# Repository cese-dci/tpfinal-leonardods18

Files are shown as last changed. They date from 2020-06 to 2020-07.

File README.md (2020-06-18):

TP Diseño de Circuitos Impresos [CESE 10Co2019]

Autor: Del Sancio Leonardo Daniel   -  Alumno revisor: Yapura Alberto  - Docente Revisor: Diego Brengi

Nombre del proyecto: MÓDEM ENERGY METER
Descripción del proyecto: Este proyecto consiste en tomar lecturas de tensión y corrientes de equipos trifásicos y trasnsmitirlas por 
Wifi o bluetooth, el circuito integrado ATM90E36 es el encargado de tomar las variables físicas y trasmitirlas al ESP32 por SPI.

------------------------------------------------------------------------------------
El diseño se Realizará en la empresa fabricante de PCB JLCPCB. https://jlcpcb.com/#

En esta página podes realizar prototipos de excelente calidad por 2 dolares. 

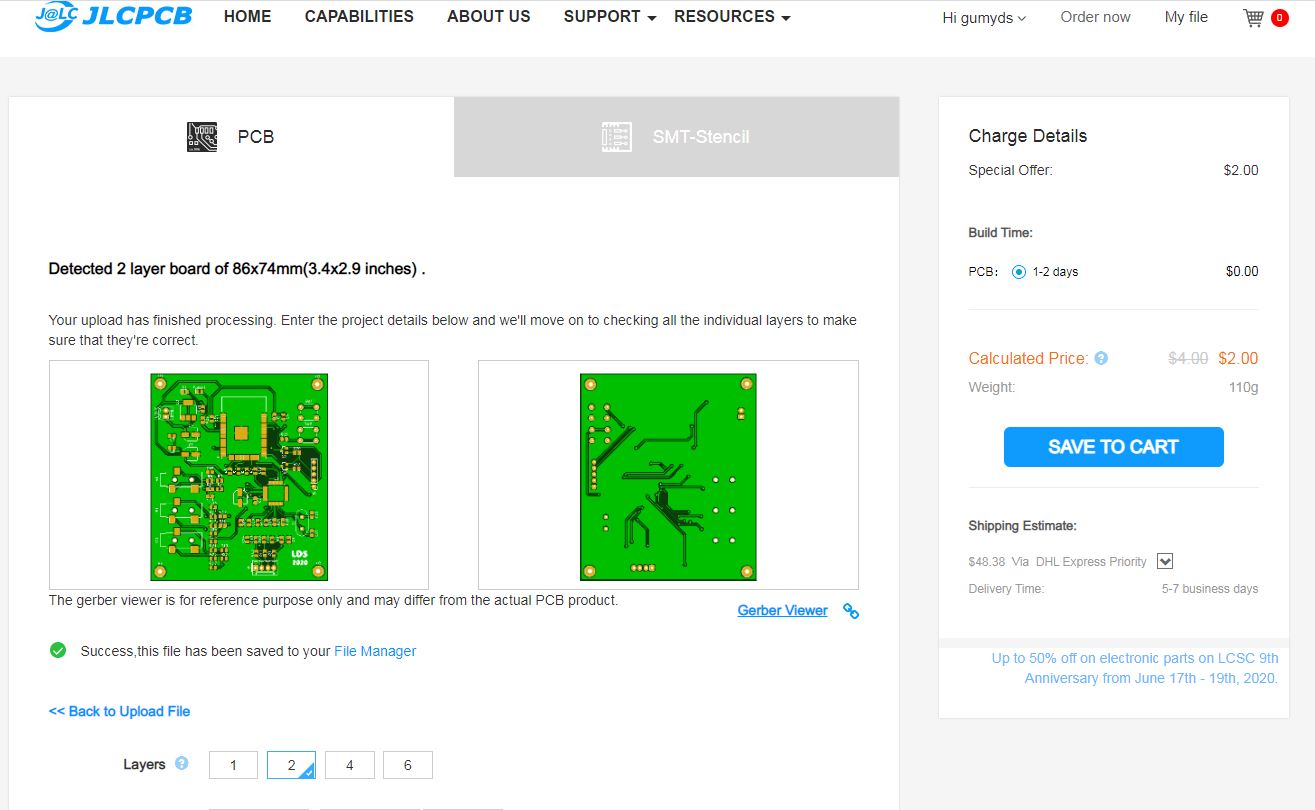
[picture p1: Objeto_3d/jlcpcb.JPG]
Optional Title


------------------------------------------------------------------------------------

NOTA: en el archivo BOM se pueden encontrar todos los componentes y su fabricante de la página MOUSER. 
https://ar.mouser.com/

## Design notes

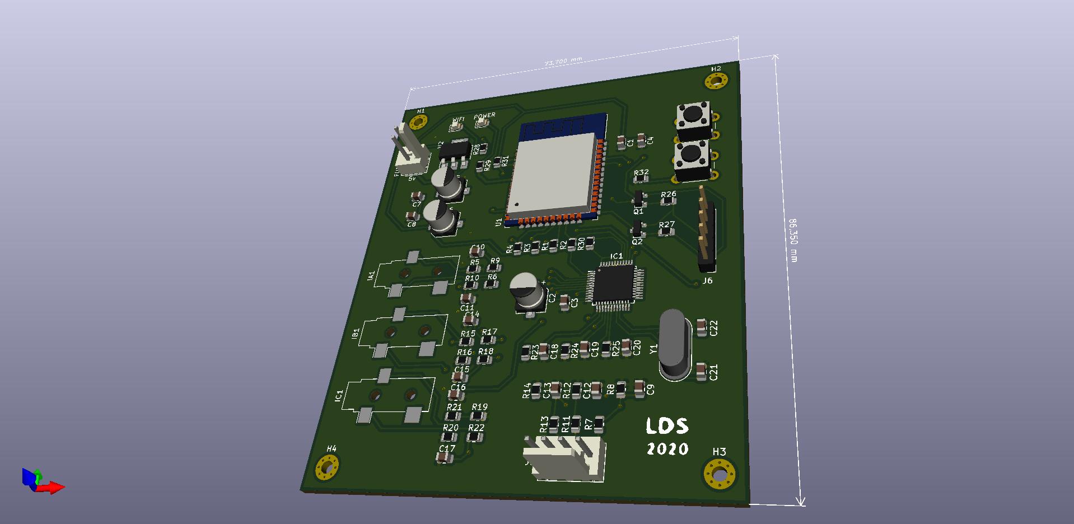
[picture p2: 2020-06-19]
Objeto_3d/Energy_Meter2.jpg

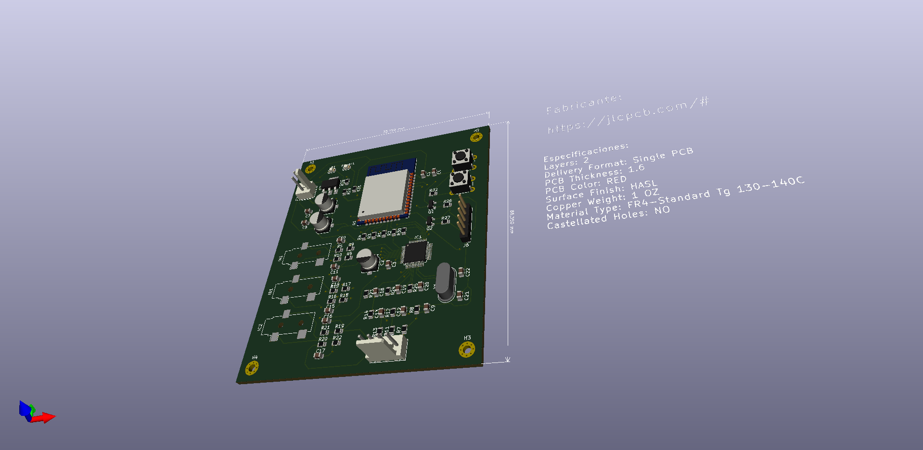
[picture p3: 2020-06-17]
Objeto_3d/Energy_Meter.png

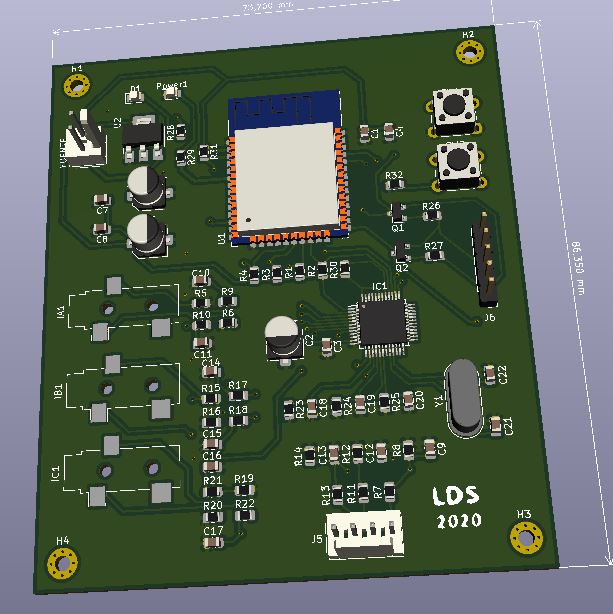
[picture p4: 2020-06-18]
Objeto_3d/Captura.JPG

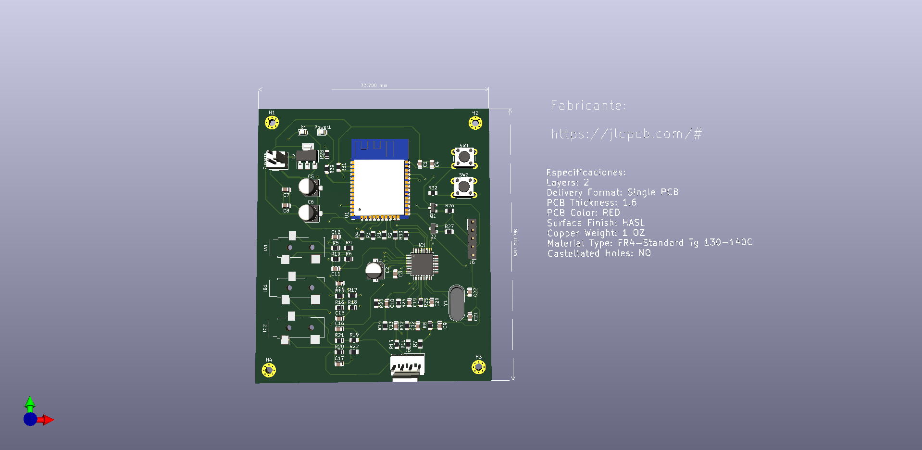
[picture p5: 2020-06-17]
Objeto_3d/Energy_Meter2.png

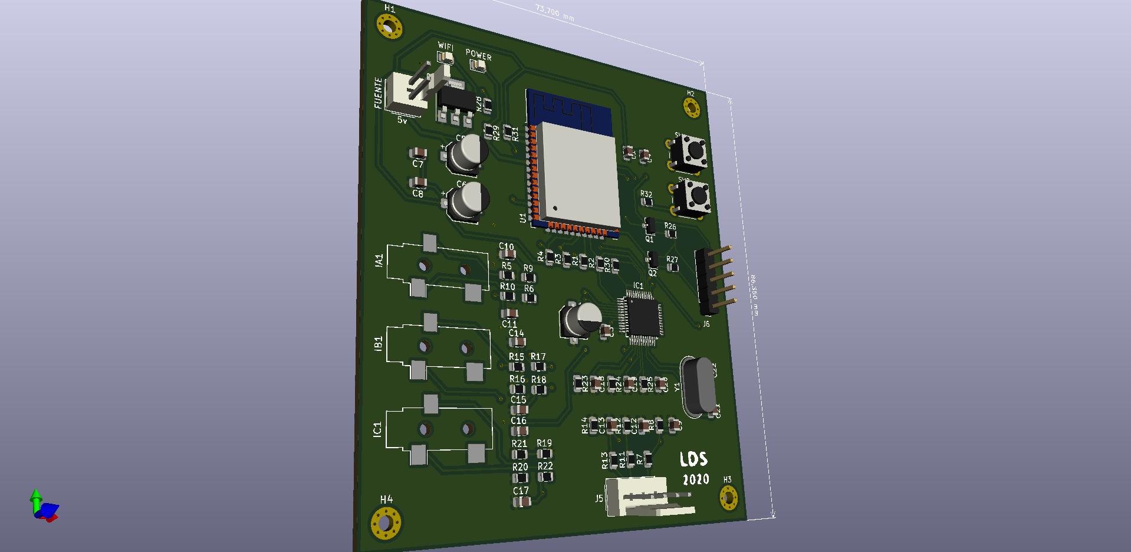
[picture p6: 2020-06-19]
Objeto_3d/Energy_Meter3.jpg

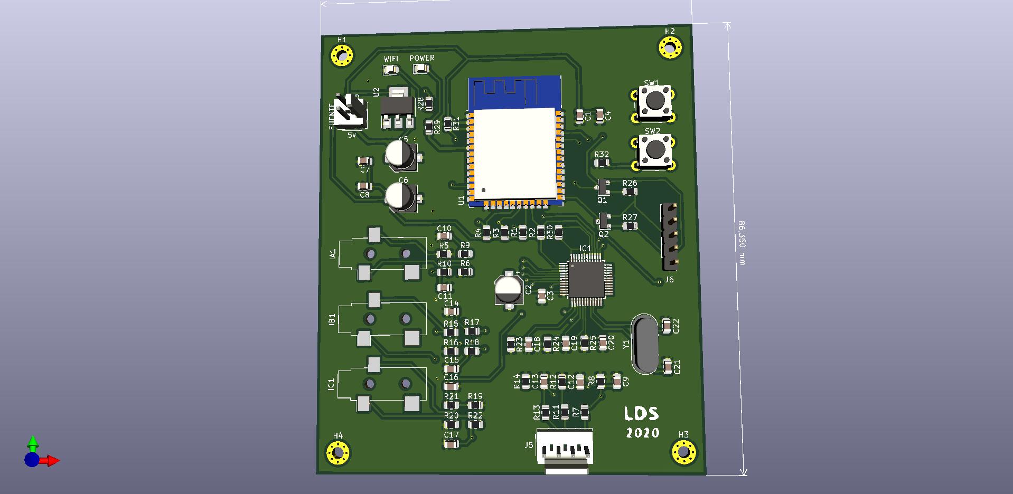
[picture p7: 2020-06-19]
Objeto_3d/Energy_Meter.jpg

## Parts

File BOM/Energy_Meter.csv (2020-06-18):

Id | Identificador | Empaquetado | Cantidad | IdentificaciÃ³n | Fabricante | Descripcion
1 | G*** | fiuba | 1 | LOGO
2 | Y1 | Crystal_HC49-4H_Vertical | 1 | 16.384MHz
3 | U2 | SOT-223-3_TabPin2 | 1 | LD1117S18TR_SOT223
4 | U1 | ESP32-WROOM-32 | 1 | ESP32-WROOM-32D | ESP32-WROOM-32D (4MB) | Módulos WiFi (802.11) SMD Module, ESP32-D0WD, 32Mbits SPI flash, UART mode, PCB
5 | C9,C10,C11,C12,C13,C14,C15,C16,C17,C18,C19,C20 | C_0805_2012Metric | 12 | 18nF | VJ0805Y181KXAPW1BC | Capacitores cerámicos de capas múltiples (MLCC) - SMD/SMT 0805 180pF 50volts
6 | C1,C3,C4,C7 | C_0805_2012Metric | 4 | 100nF | 885012207128 | Capacitores cerámicos de capas múltiples (MLCC) - SMD/SMT WCAP-CSGP 100V 0.1uF 0805 10%
7 | C2,C5,C6 | CP_Elec_5x5.3 | 3 | 10uF
8 | C8 | C_0805_2012Metric | 1 | 47nF
9 | C21,C22 | C_0805_2012Metric | 2 | 22pF
10 | IA1 | Jack_3.5mm_CUI_SJ-3523-SMT_Horizontal | 1 | Corriente A | SJ-3523-SMT-TR | Conectores de teléfono Audio Jacks
11 | IB1 | Jack_3.5mm_CUI_SJ-3523-SMT_Horizontal | 1 | Corriente B | SJ-3523-SMT-TR | Conectores de teléfono Audio Jacks
12 | IC1 | TQFP-48_7x7mm_P0.5mm | 1 | ATM90E36 | ATM90E36A-AU-Y | Entrada analógica - AFE 48-TQFP, IND TEMP 1.8V/3V
13 | IC1 | Jack_3.5mm_CUI_SJ-3523-SMT_Horizontal | 1 | Corriente C | SJ-3523-SMT-TR | Conectores de teléfono Audio Jacks
14 | FUENTE | Molex_KK-254_AE-6410-02A_1x02_P2.54mm_Vertical | 1 | Conn_01x02_Male
15 | J5 | Molex_KK-254_AE-6410-04A_1x04_P2.54mm_Vertical | 1 | TENSION
16 | J6 | PinHeader_1x05_P2.54mm_Vertical | 1 | PROGRAMACION
17 | Q1,Q2 | SOT-23 | 2 | BC817
18 | R1,R2,R3,R4,R26,R27,R30,R31 | R_0805_2012Metric | 8 | 10K
19 | R5,R6,R15,R16,R19,R20 | R_0805_2012Metric | 6 | 2.4
20 | R7,R11,R13 | R_0805_2012Metric | 3 | 100K
21 | R8,R9,R10,R12,R14,R17,R18,R21,R22,R23,R24,R25 | R_0805_2012Metric | 12 | 1K | CRCW08051K00FKEAC | Resistores de película gruesa - SMD 1/8Watt 1Kohms 1%
22 | D1 | LED_0805_2012Metric | 1 | ConexiÃ³n | AP2012HD | LED estándar - SMD (montaje superficial) RED DIFFUSED
23 | Power1 | LED_0805_2012Metric | 1 | LED | AP2012HD | LED estándar - SMD (montaje superficial) RED DIFFUSED
24 | R28,R29 | R_0805_2012Metric | 2 | 560
25 | R32 | R_0805_2012Metric | 1 | 50R
26 | SW1 | SW_PUSH_6mm_H4.3mm | 1 | RESET
27 | SW2 | SW_PUSH_6mm_H4.3mm | 1 | PR
28 | H1,H2,H3,H4 | MountingHole_2.2mm_M2_Pad_Via | 4 | MountingHole

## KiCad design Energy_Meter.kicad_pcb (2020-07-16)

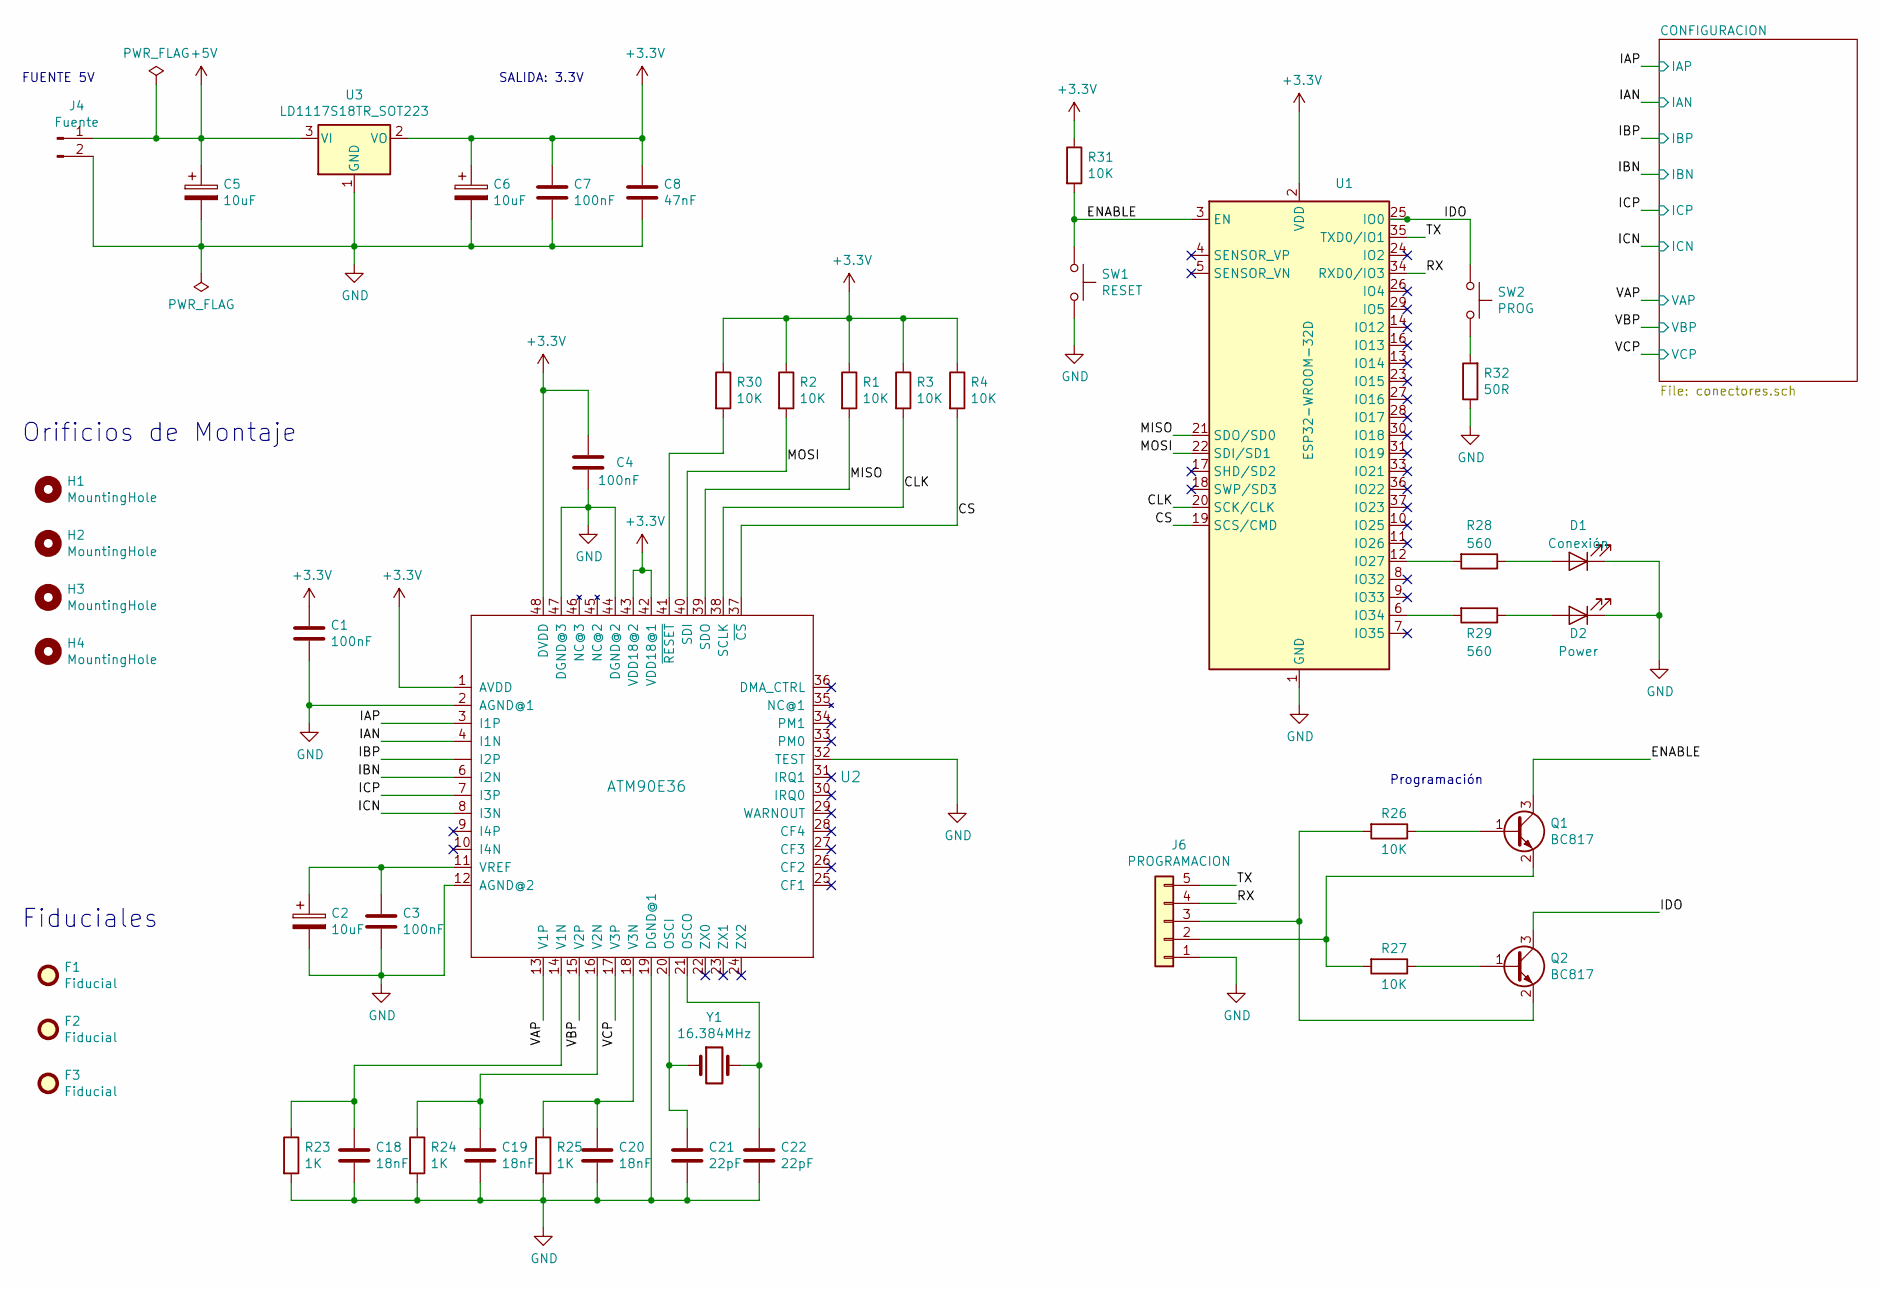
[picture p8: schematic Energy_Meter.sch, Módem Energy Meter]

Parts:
C1, C3, C4, C7: 100nF; C_0805_2012Metric
C2, C5, C6: 10uF; CP_Elec_5x5.3
C8: 47nF; C_0805_2012Metric
C18, C19, C20: 18nF; C_0805_2012Metric
C21, C22: 22pF; C_0805_2012Metric
D1: Conexión; LED_0805_2012Metric
D2: Power; LED_0805_2012Metric
F1, F2, F3: Fiducial; Fiducial_0.5mm_Mask1.5mm
H1, H2, H3, H4: MountingHole; MountingHole_2.2mm_M2_Pad_Via
J4: Fuente; Molex_KK-254_AE-6410-02A_1x02_P2.54mm_Vertical
J6: PROGRAMACION; PinHeader_1x05_P2.54mm_Vertical
Q1: BC817; SOT-23; Mouser 771-BC817K-40HVL
Q2: BC817; SOT-23; Mouser 771-BC817K-16HR
R1, R2, R3, R4, R26, R27, R30, R31: 10K; R_0805_2012Metric
R23, R24, R25: 1K; R_0805_2012Metric
R28, R29: 560; R_0805_2012Metric
R32: 50R; R_0805_2012Metric
SW1: RESET; SW_PUSH_6mm_H4.3mm
SW2: PROG; SW_PUSH_6mm_H4.3mm
U1: ESP32-WROOM-32D; ESP32-WROOM-32; Mouser 356-ESP32WRM32E132PH
U2: ATM90E36; TQFP-48_7x7mm_P0.5mm; Mouser 556-ATM90E36A-AU-Y
U3: LD1117S18TR_SOT223; SOT-223-3_TabPin2; Mouser 511-LD1117AS18
Y1: 16.384MHz; Crystal_HC49-4H_Vertical; Digikey XC2790TR-ND

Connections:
+3V3: C1.1, C4.1, C6.1, C7.1, C8.1, R1.1, R2.1, R3.1, R4.1, R30.1, R31.1, U1.2 (VDD), U2.1 (AVDD), U2.42 (VDD18@1), U2.43 (VDD18@2), U2.48 (DVDD), U3.2 (VO)
+5V: C5.1, J4.1, U3.3 (VI)
/CLK: R3.2, U1.20 (SCK/CLK), U2.38 (SCLK)
/CS: R4.2, U1.19 (SCS/CMD), U2.37 (~CS)
/ENABLE: Q1.3 (C), R31.2, SW1.1, U1.3 (EN)
/IAN: U2.4 (I1N); also elsewhere on the board
/IAP: U2.3 (I1P); also elsewhere on the board
/IBN: U2.6 (I2N); also elsewhere on the board
/IBP: U2.5 (I2P); also elsewhere on the board
/ICN: U2.8 (I3N); also elsewhere on the board
/ICP: U2.7 (I3P); also elsewhere on the board
/IDO: Q2.3 (C), SW2.1, U1.25 (IO0)
/MISO: R1.2, U1.21 (SDO/SD0), U2.39 (SDO)
/MOSI: R2.2, U1.22 (SDI/SD1), U2.40 (SDI)
/RX: J6.4, U1.34 (RXD0/IO3)
/TX: J6.5, U1.35 (TXD0/IO1)
/VAP: U2.13 (V1P); also elsewhere on the board
/VBP: U2.15 (V2P); also elsewhere on the board
/VCP: U2.17 (V3P); also elsewhere on the board
GND: C1.2, C2.2, C3.2, C4.2, C5.2, C6.2, C7.2, C8.2, C18.2, C19.2, C20.2, C21.2, C22.2, D1.1 (K), D2.1 (K), J4.2, J6.1, R23.2, R24.2, R25.2, R32.1, SW1.2, U1.1 (GND), U1.15 (GND), U1.38 (GND), U1.39 (GND), U2.2 (AGND@1), U2.12 (AGND@2), U2.19 (DGND@1), U2.32 (TEST), U2.44 (DGND@2), U2.47 (DGND@3), U3.1 (GND); also elsewhere on the board
unnamed: C2.1, C3.1, U2.11 (VREF)
unnamed: C18.1, R23.1, U2.14 (V1N)
unnamed: C19.1, R24.1, U2.16 (V2N)
unnamed: C20.1, R25.1, U2.18 (V3N)
unnamed: C21.1, U2.20 (OSCI), Y1.1
unnamed: C22.1, U2.21 (OSCO), Y1.2
unnamed: D1.2 (A), R28.1
unnamed: D2.2 (A), R29.1
unnamed: J6.2, Q1.2 (E), R27.2
unnamed: J6.3, Q2.2 (E), R26.2
unnamed: Q1.1 (B), R26.1
unnamed: Q2.1 (B), R27.1
unnamed: R28.2, U1.12 (IO27)
unnamed: R29.2, U1.6 (IO34)
unnamed: R30.2, U2.41 (~RESET)
unnamed: R32.2, SW2.2

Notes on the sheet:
Programación
SALIDA: 3.3V
FUENTE 5V
Orificios de Montaje
Fiduciales

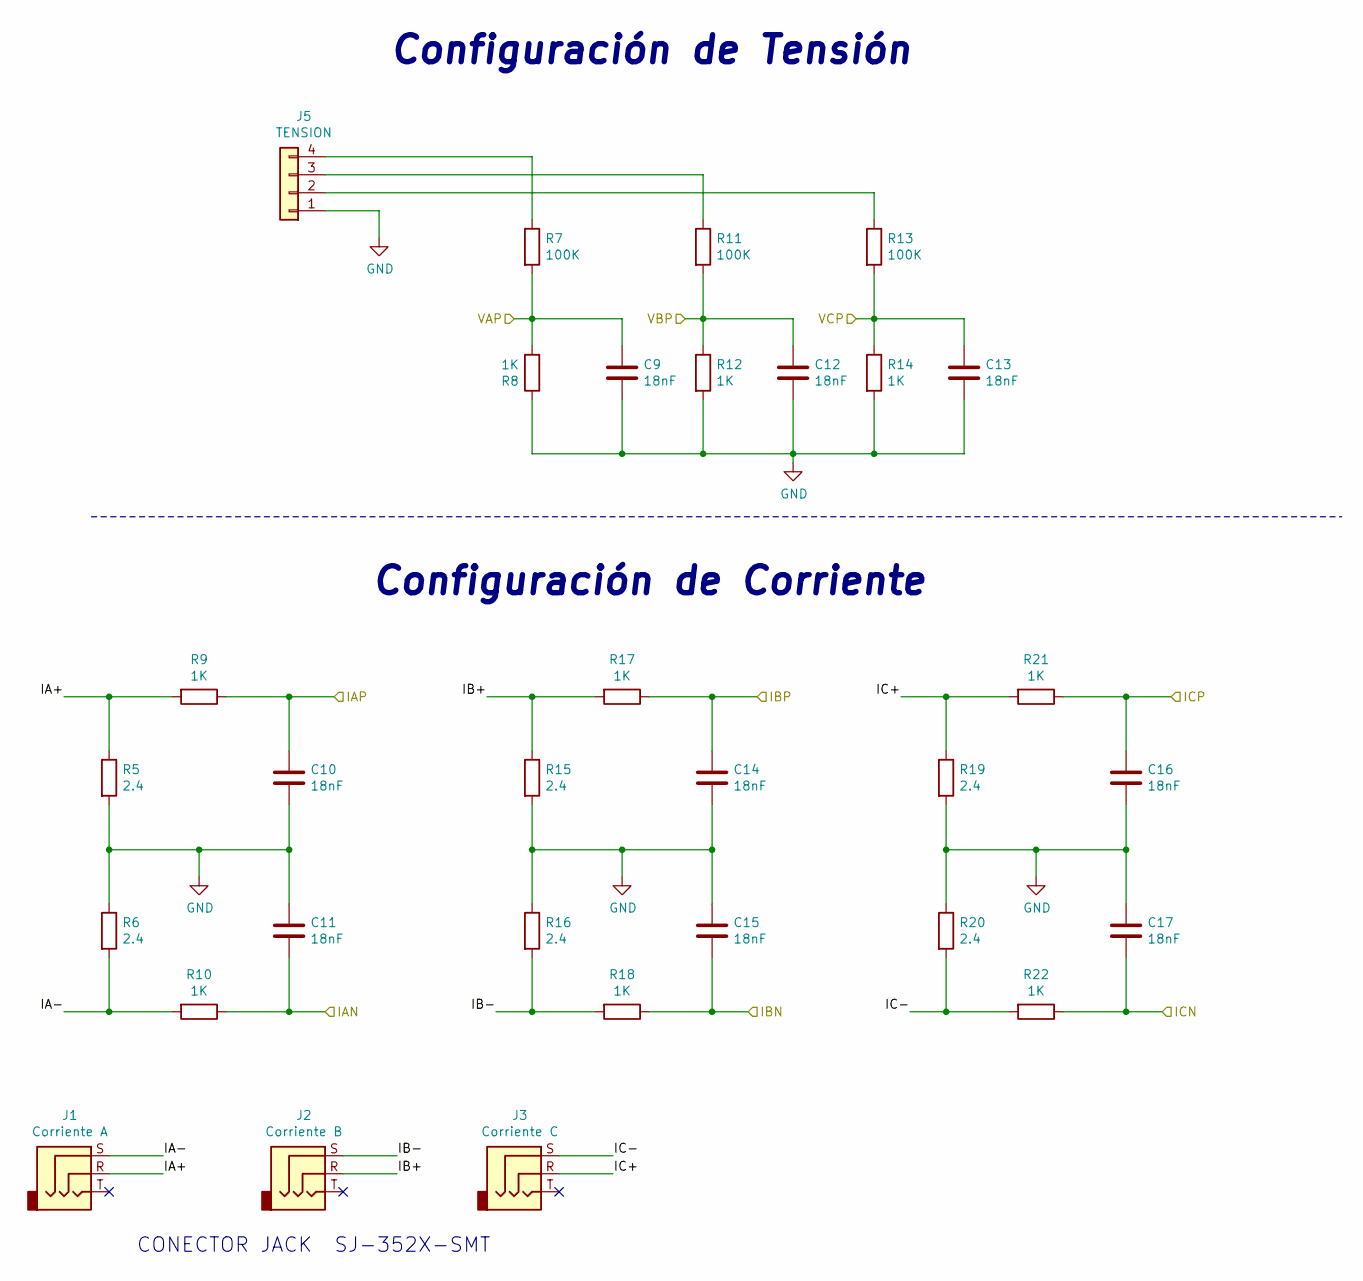
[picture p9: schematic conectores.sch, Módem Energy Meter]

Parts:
C9, C10, C11, C12, C13, C14, C15, C16, C17: 18nF; C_0805_2012Metric
J1: Corriente A; Jack_3.5mm_CUI_SJ-3523-SMT_Horizontal
J2: Corriente B; Jack_3.5mm_CUI_SJ-3523-SMT_Horizontal
J3: Corriente C; Jack_3.5mm_CUI_SJ-3523-SMT_Horizontal
J5: TENSION; Molex_KK-254_AE-6410-04A_1x04_P2.54mm_Vertical
R5, R6, R15, R16, R19, R20: 2.4; R_0805_2012Metric
R7, R11, R13: 100K; R_0805_2012Metric
R8, R9, R10, R12, R14, R17, R18, R21, R22: 1K; R_0805_2012Metric

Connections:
/CONFIGURACION/IA+: J1.R, R5.1, R9.2
/CONFIGURACION/IA-: J1.S, R6.2, R10.2
/CONFIGURACION/IB+: J2.R, R15.1, R17.2
/CONFIGURACION/IB-: J2.S, R16.2, R18.2
/CONFIGURACION/IC+: J3.R, R19.1, R21.2
/CONFIGURACION/IC-: J3.S, R20.2, R22.2
/IAN: C11.2, R10.1; also elsewhere on the board
/IAP: C10.1, R9.1; also elsewhere on the board
/IBN: C15.2, R18.1; also elsewhere on the board
/IBP: C14.1, R17.1; also elsewhere on the board
/ICN: C17.2, R22.1; also elsewhere on the board
/ICP: C16.1, R21.1; also elsewhere on the board
/VAP: C9.1, R7.2, R8.2; also elsewhere on the board
/VBP: C12.1, R11.2, R12.1; also elsewhere on the board
/VCP: C13.1, R13.2, R14.1; also elsewhere on the board
GND: C9.2, C10.2, C11.1, C12.2, C13.2, C14.2, C15.1, C16.2, C17.1, J5.1, R5.2, R6.1, R8.1, R12.2, R14.2, R15.2, R16.1, R19.2, R20.1; also elsewhere on the board
unnamed: J5.2, R13.1
unnamed: J5.3, R11.1
unnamed: J5.4, R7.1

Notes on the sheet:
Configuración de Tensión
CONECTOR JACK SJ-352X-SMT
Configuración de Corriente

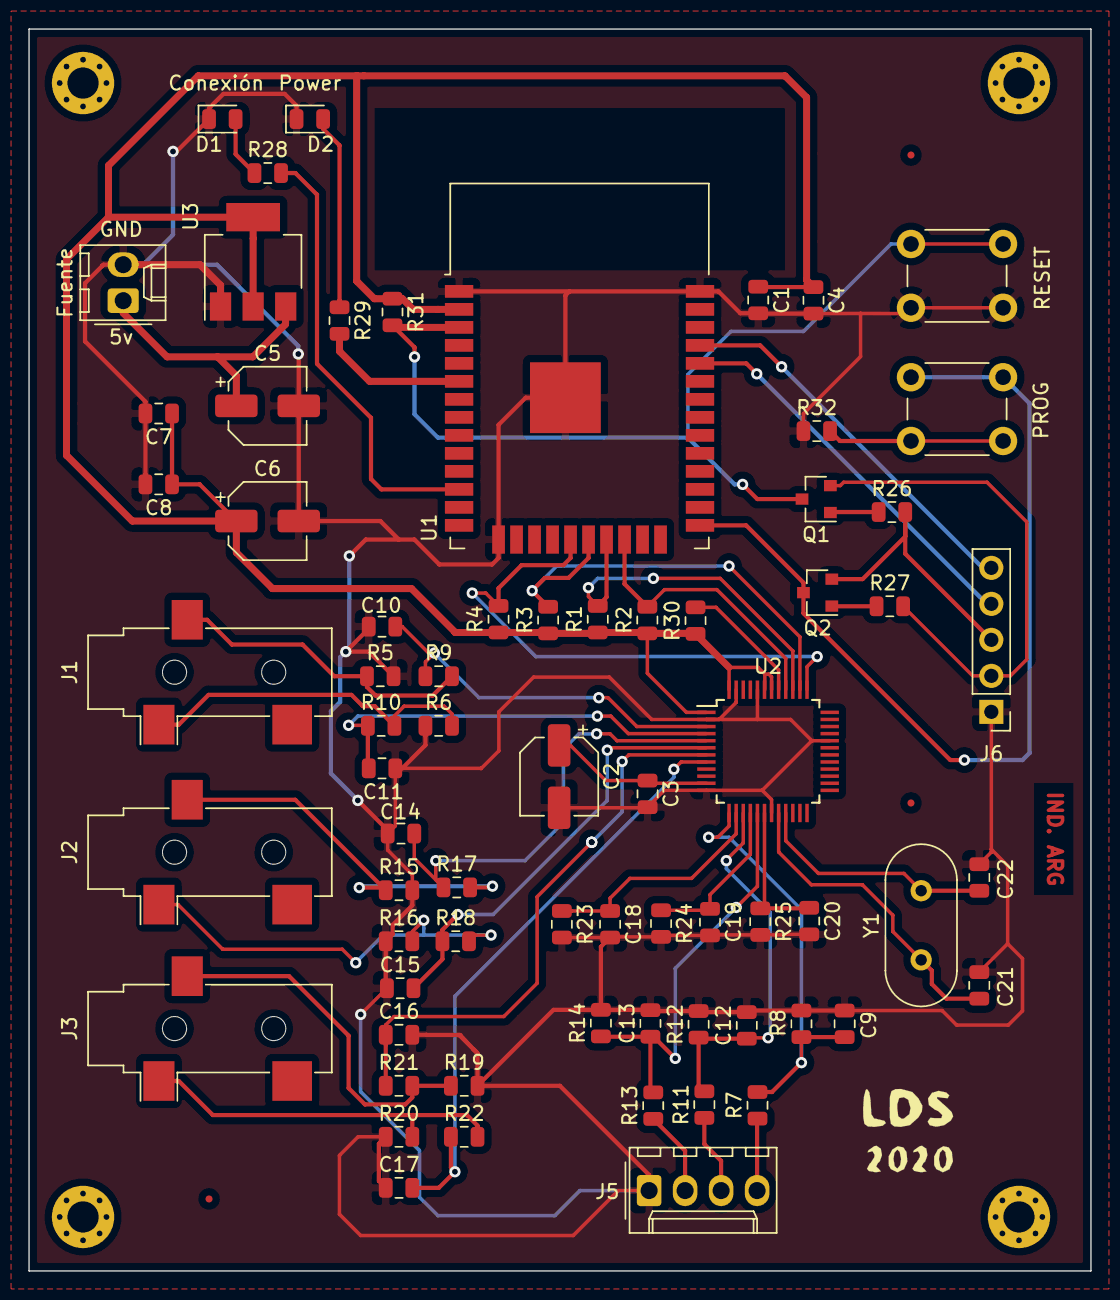
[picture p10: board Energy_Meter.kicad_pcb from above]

Board: 2 copper layers, 74.9 x 87.6 mm, 77 parts (0 on the bottom side), 45 nets.

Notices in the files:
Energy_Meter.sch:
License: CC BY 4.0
